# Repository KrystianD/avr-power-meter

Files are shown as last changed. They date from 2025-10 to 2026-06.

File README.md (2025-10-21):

avr-power-meter
======

Device for monitoring bidirectional DC energy usage using various shunt resistors. Designed to mount directly on the shunt.

This version targets 48 V systems (supports up to 85 V on the sensing side).

It is galvanically isolated from the power supply to prevent ground loops.

It communicates via the Modbus RTU protocol over an RS-485 interface.

The core components are the `INA228` sensor and an `ATtiny1626` microcontroller.

### History

See the v1 (test) version in [[v1]](https://github.com/KrystianD/avr-power-meter/tree/v1) branch. \
See the v2 (for 24V systems) version in [[v2]](https://github.com/KrystianD/avr-power-meter/tree/v2) branch.

# Board

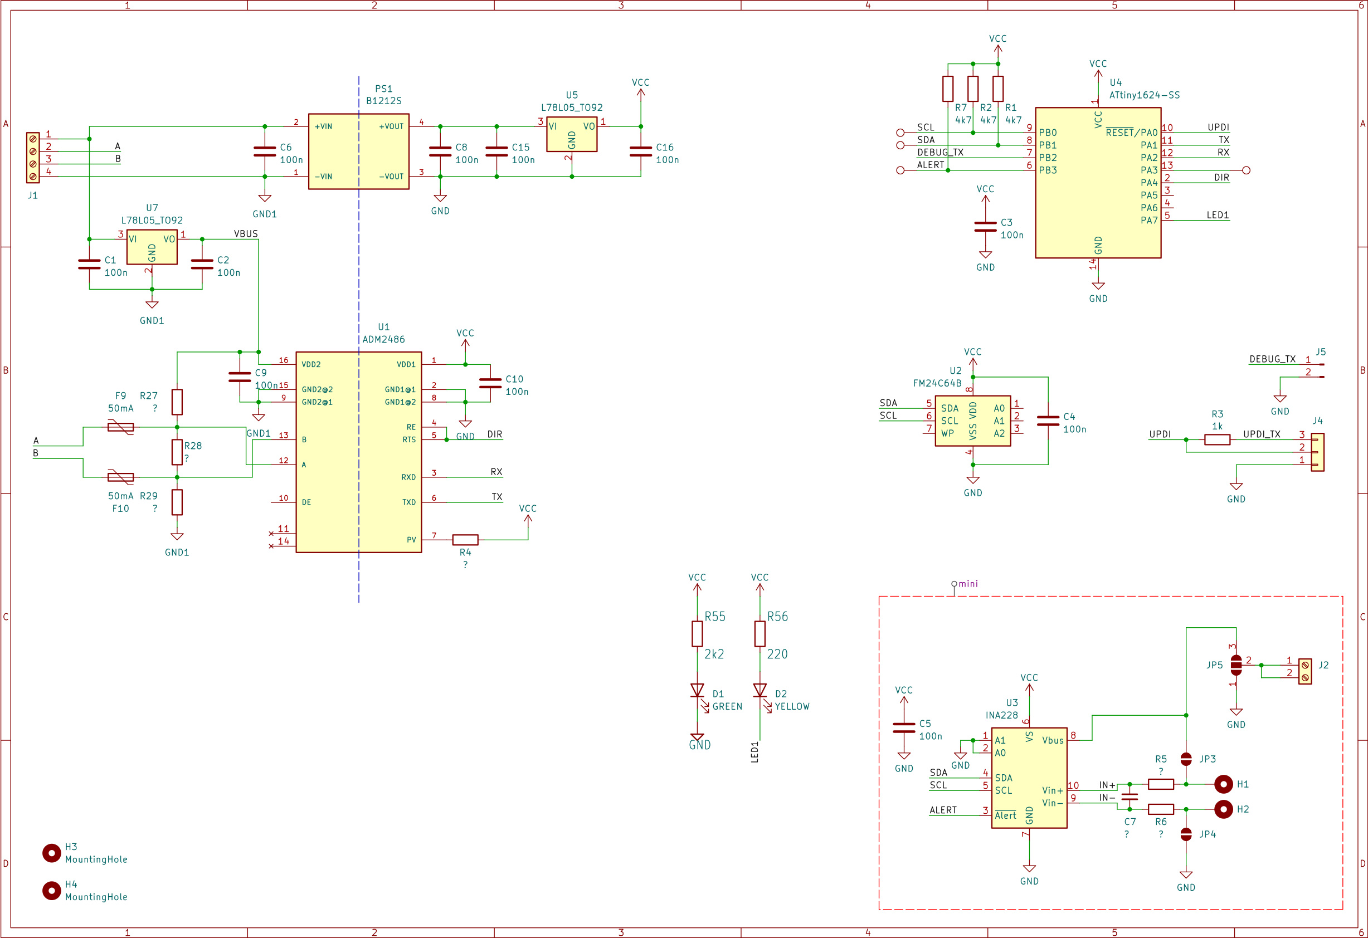
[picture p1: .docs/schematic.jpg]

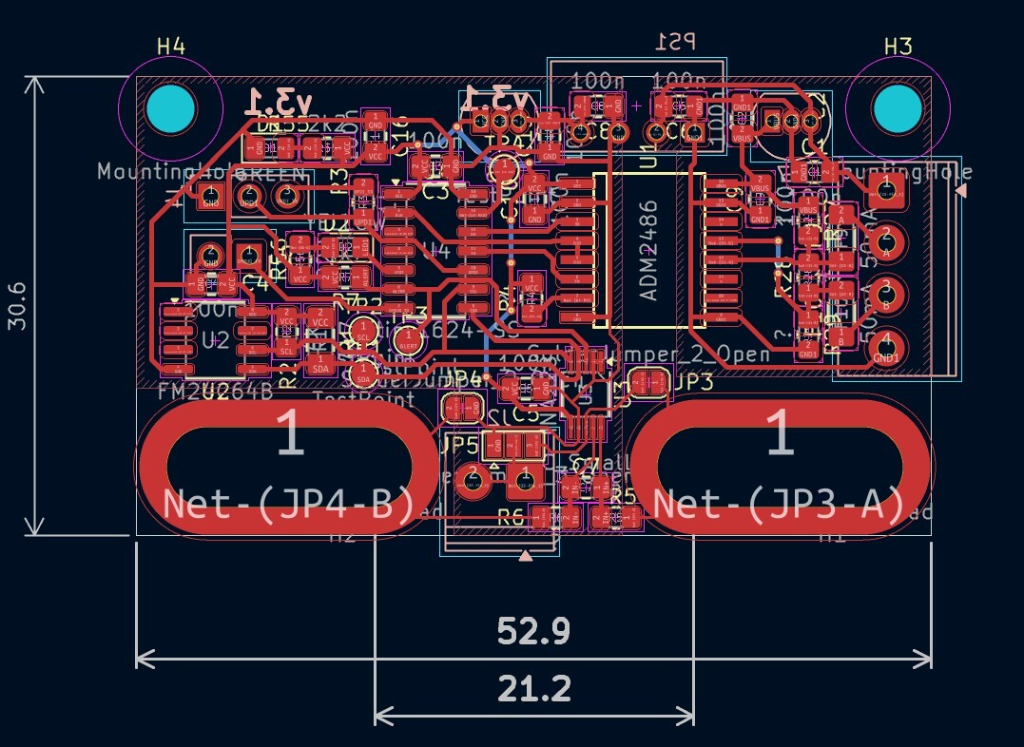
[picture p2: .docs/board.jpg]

<br/>
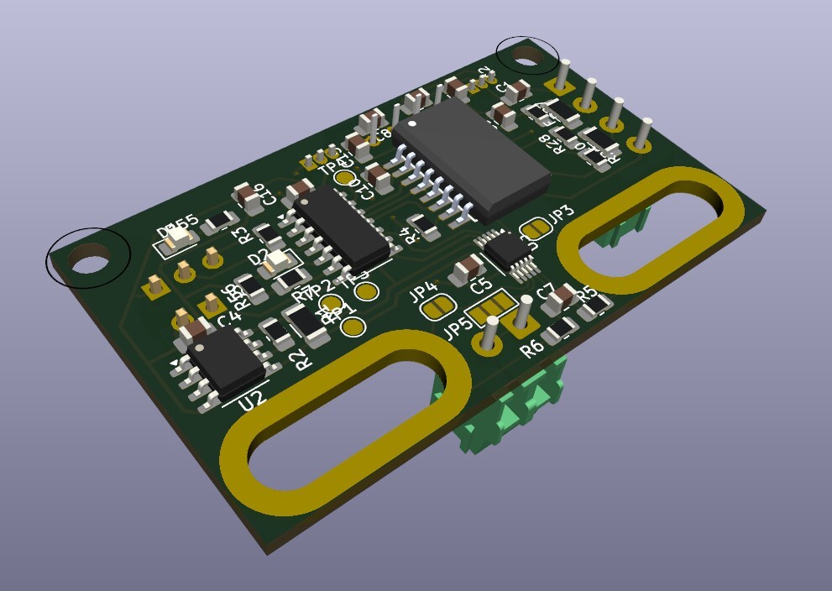
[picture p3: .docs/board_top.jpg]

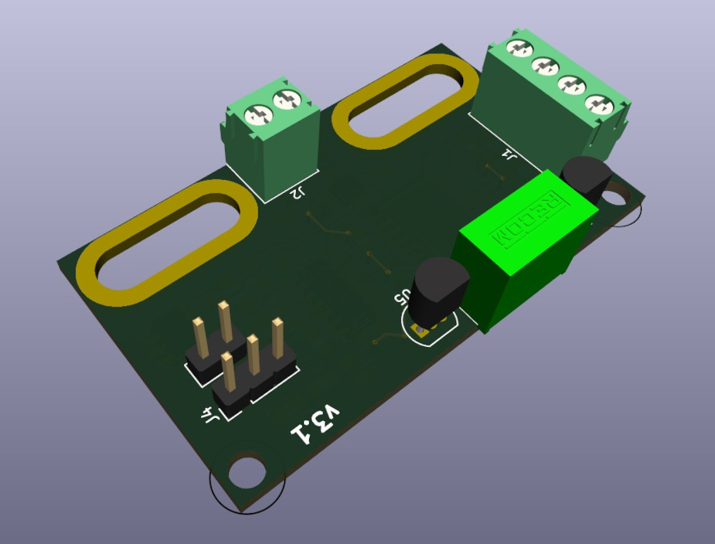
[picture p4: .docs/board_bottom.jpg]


# Photos

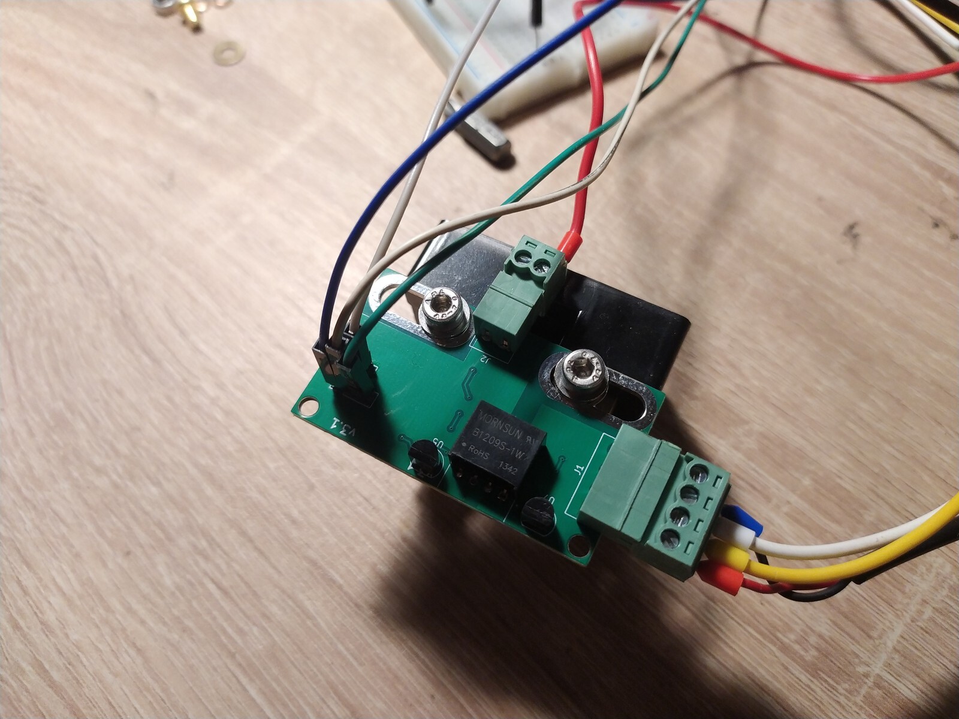
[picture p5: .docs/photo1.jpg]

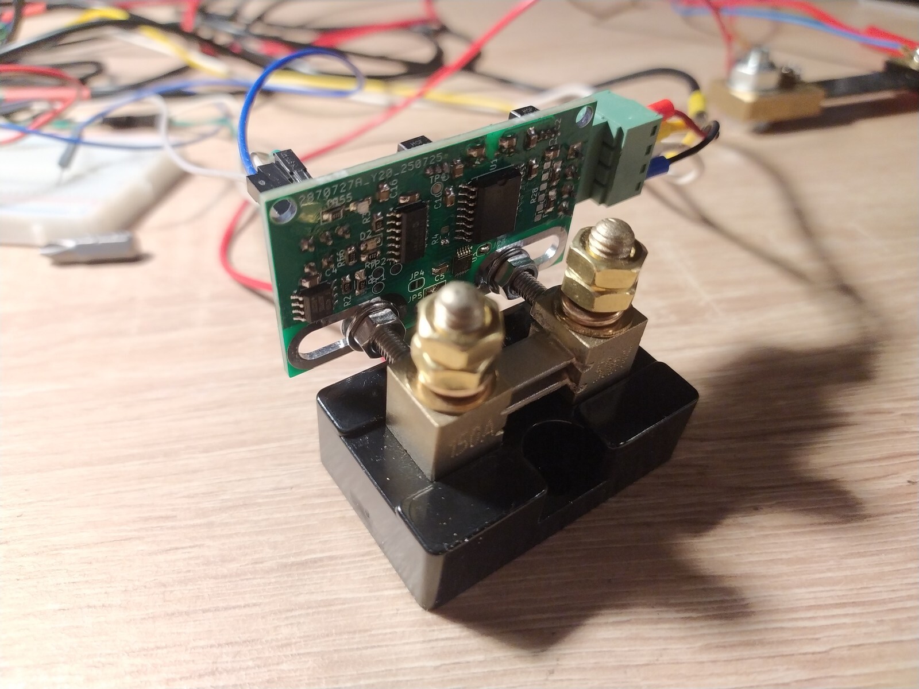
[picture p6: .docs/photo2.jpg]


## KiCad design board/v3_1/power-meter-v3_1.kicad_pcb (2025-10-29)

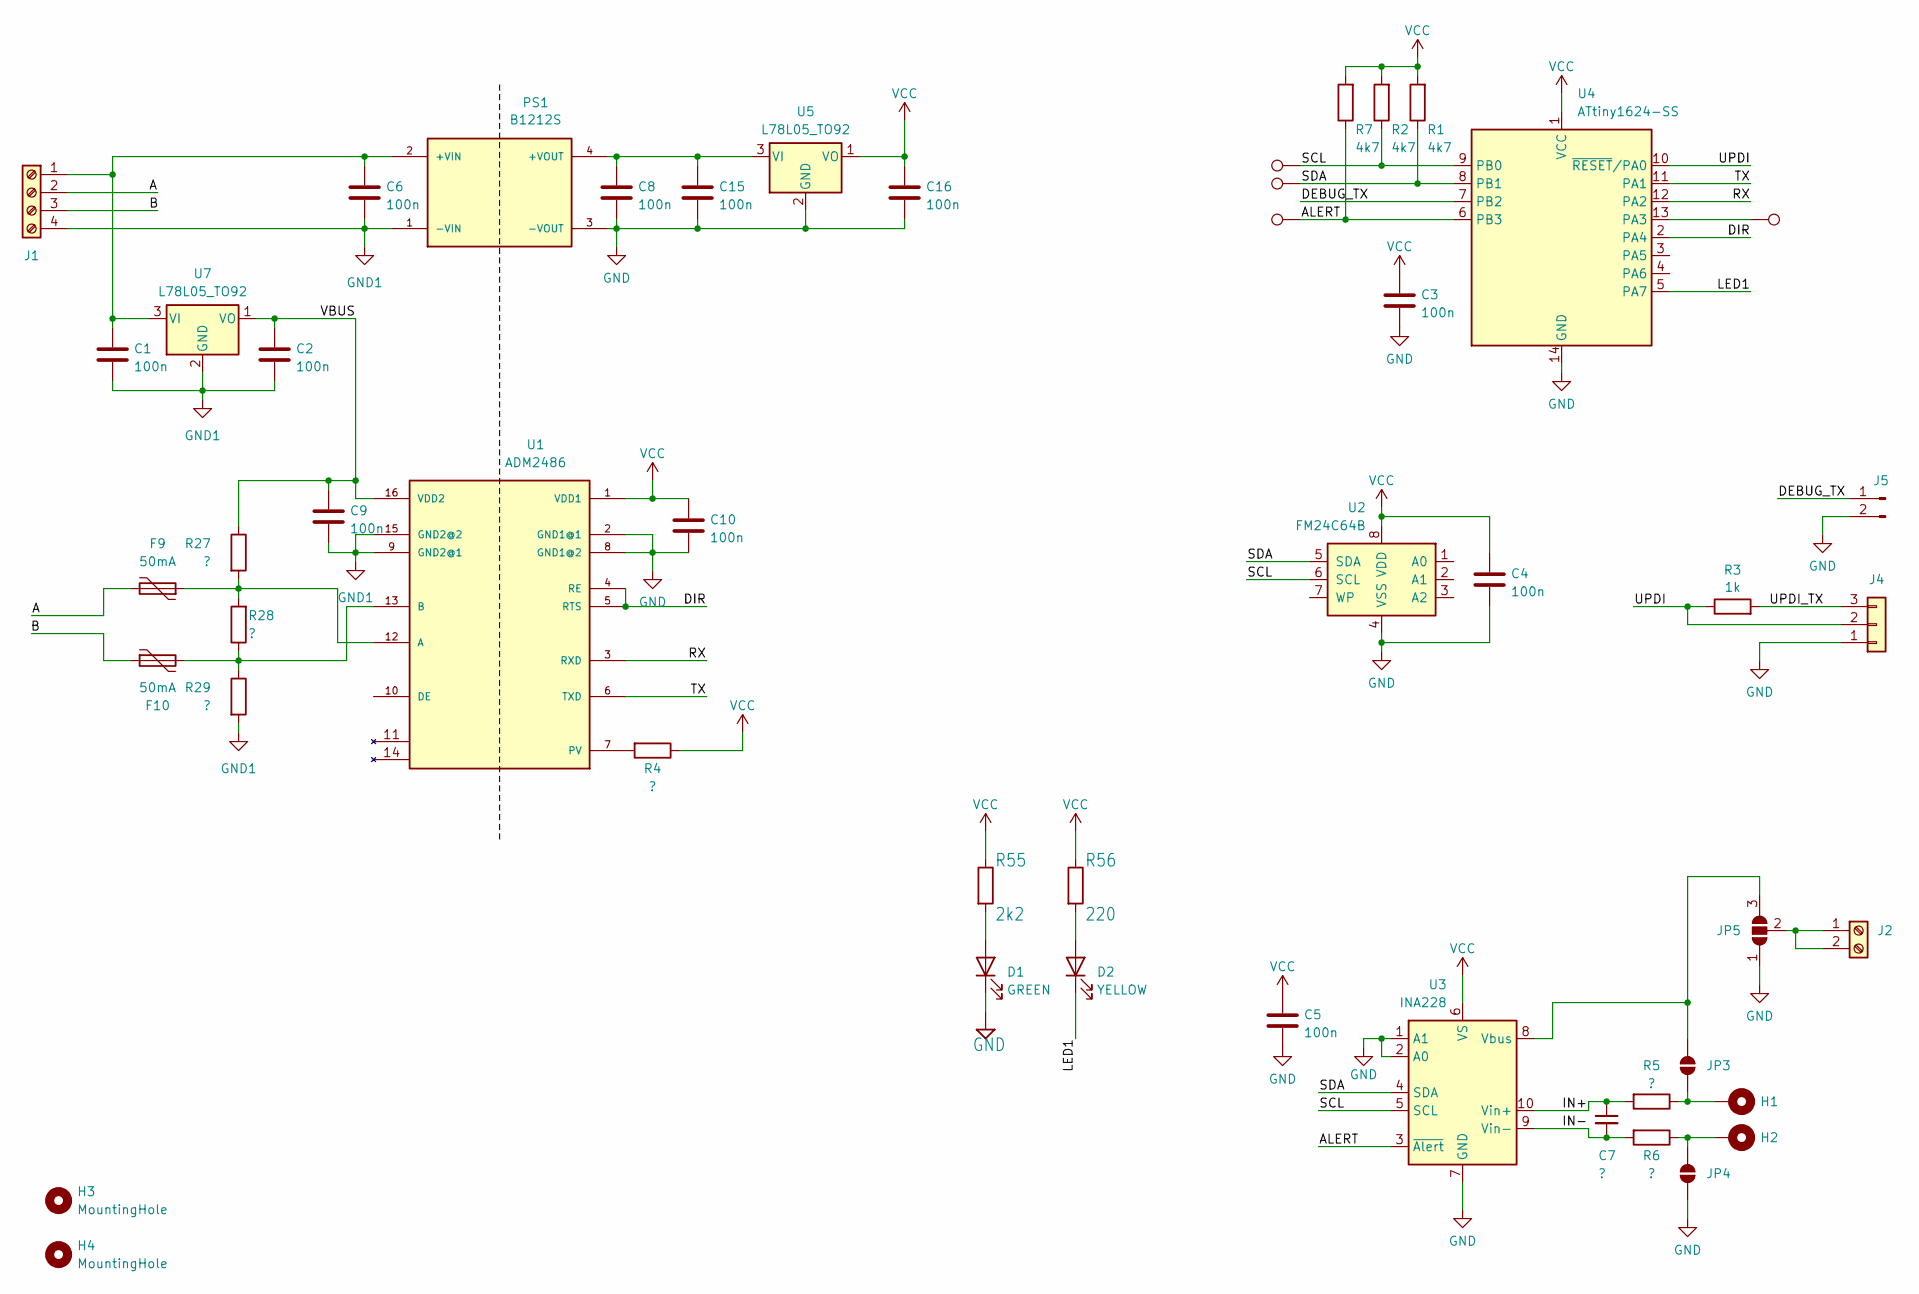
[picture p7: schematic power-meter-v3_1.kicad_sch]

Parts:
C1, C2, C3, C4, C5, C6, C8, C9, C10, C15, C16: 100n; C_0805_2012Metric_Pad1.18x1.45mm_HandSolder
C7: ?; C_0805_2012Metric_Pad1.18x1.45mm_HandSolder
D1: GREEN; LED_0805_2012Metric_Pad1.15x1.40mm_HandSolder
D2: YELLOW; LED_0805_2012Metric_Pad1.15x1.40mm_HandSolder
F9, F10: 50mA; R_1206_3216Metric_Pad1.30x1.75mm_HandSolder
H1, H2: MountingHole_Pad; M5-shunt-pad
H3, H4: MountingHole; MountingHole_3.2mm_M3
J1: Screw_Terminal_01x04; TerminalBlock_Phoenix_PT-1,5-4-3.5-H_1x04_P3.50mm_Horizontal
J2: Screw_Terminal_01x02; TerminalBlock_Phoenix_PT-1,5-2-3.5-H_1x02_P3.50mm_Horizontal
J4: Conn_01x03; PinHeader_1x03_P2.54mm_Vertical
J5: Conn_01x02_Pin; PinHeader_1x02_P2.54mm_Vertical
JP3, JP4: SolderJumper_2_Open; SolderJumper-2_P1.3mm_Open_RoundedPad1.0x1.5mm
JP5: SolderJumper_3_Open; SolderJumper-3_P1.3mm_Open_Pad1.0x1.5mm
PS1: B1212S; CONV_RO-0505S; PARTREV 3
R1: 4k7; R_1206_3216Metric_Pad1.30x1.75mm_HandSolder
R2, R7: 4k7; R_0805_2012Metric_Pad1.20x1.40mm_HandSolder
R3: 1k; R_0805_2012Metric_Pad1.20x1.40mm_HandSolder
R4, R5, R6, R27, R28, R29: ?; R_0805_2012Metric_Pad1.20x1.40mm_HandSolder
R55: 2k2; R_0805_2012Metric_Pad1.20x1.40mm_HandSolder
R56: 220; R_0805_2012Metric_Pad1.20x1.40mm_HandSolder
TP1, TP2, TP3, TP4: TestPoint; TestPoint_Pad_D1.5mm
U1: ADM2486; SOIC16R
U2: FM24C64B; SOIC-8_3.9x4.9mm_P1.27mm
U3: INA228; VSSOP-10_3x3mm_P0.5mm
U4: ATtiny1624-SS; SOIC-14_3.9x8.7mm_P1.27mm
U5, U7: L78L05_TO92; TO-92_Inline

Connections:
/A: F9.2, J1.2
/ALERT: R7.1, TP3.1 (1_1), U3.3 (~Alert), U4.6 (PB3)
/B: F10.1, J1.3
/DEBUG_TX: J5.1, U4.7 (PB2)
/DIR: U1.4 (RE), U1.5 (RTS), U4.2 (PA4)
/IN+: C7.1, R5.2, U3.10 (Vin+)
/IN-: C7.2, R6.2, U3.9 (Vin-)
/LED1: D2.1 (K), U4.5 (PA7)
/RX: U1.3 (RXD), U4.12 (PA2)
/SCL: R2.1, TP2.1 (1_1), U2.6 (SCL), U3.5 (SCL), U4.9 (PB0)
/SDA: R1.1, TP1.1 (1_1), U2.5 (SDA), U3.4 (SDA), U4.8 (PB1)
/TX: U1.6 (TXD), U4.11 (PA1)
/UPDI: J4.2, R3.1, U4.10 (~RESET/PA0)
/UPDI_TX: J4.3, R3.2
/VBUS: C2.2, C9.2, R27.1, U1.16 (VDD2), U7.1 (VO)
GND: C3.1, C4.1, C5.1, C8.1, C10.1, C15.1, C16.1, D1.1 (K), J4.1, J5.2, JP4.1 (A), JP5.1 (A), PS1.3 (-VOUT), U1.2 (GND1@1), U1.8 (GND1@2), U2.4 (VSS), U3.1 (A1), U3.2 (A0), U3.7 (GND), U4.14 (GND), U5.2 (GND)
GND1: C1.1, C2.1, C6.1, C9.1, J1.4, PS1.1 (-VIN), R29.2, U1.9 (GND2@1), U1.15 (GND2@2), U7.2 (GND)
unnamed: D1.2 (A), R55.2
unnamed: D2.2 (A), R56.2
unnamed: C1.2, C6.2, J1.1, PS1.2 (+VIN), U7.3 (VI)
unnamed: J2.1, J2.2, JP5.2 (C)
unnamed: H1.1 (1_1), JP3.1 (A), R5.1
unnamed: JP3.2 (B), JP5.3 (B), U3.8 (Vbus)
unnamed: H2.1 (1_1), JP4.2 (B), R6.1
unnamed: C8.2, C15.2, PS1.4 (+VOUT), U5.3 (VI)
unnamed: F9.1, R27.2, R28.2, U1.12 (A)
unnamed: F10.2, R28.1, R29.1, U1.13 (B)
unnamed: R4.2, U1.7 (PV)
unnamed: TP4.1 (1_1), U4.13 (PA3)
VCC: C3.2, C4.2, C5.2, C10.2, C16.2, R1.2, R2.2, R4.1, R7.2, R55.1, R56.1, U1.1 (VDD1), U2.8 (VDD), U3.6 (VS), U4.1 (VCC), U5.1 (VO)

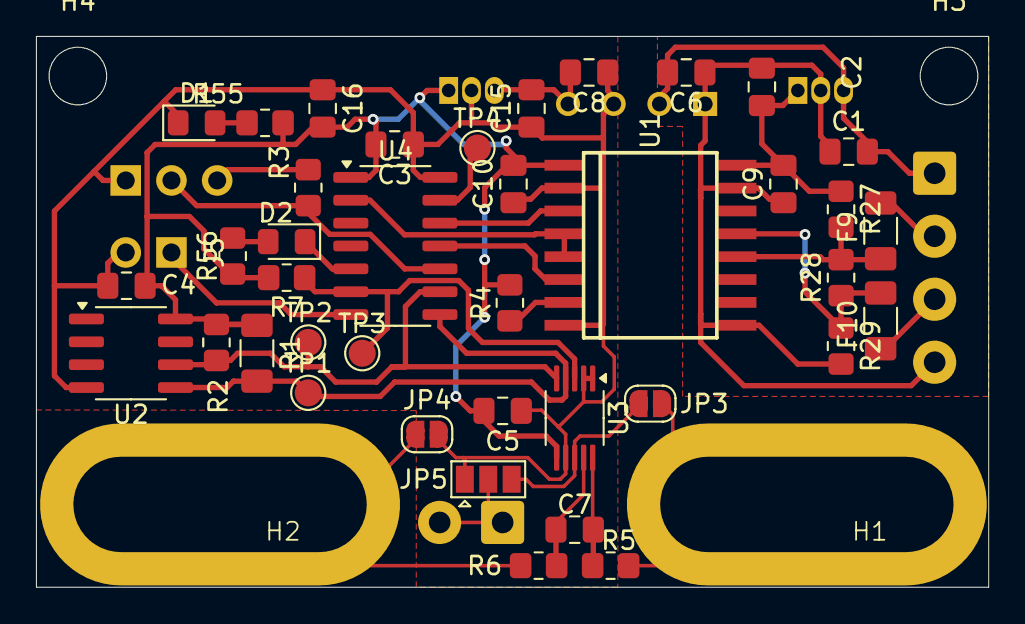
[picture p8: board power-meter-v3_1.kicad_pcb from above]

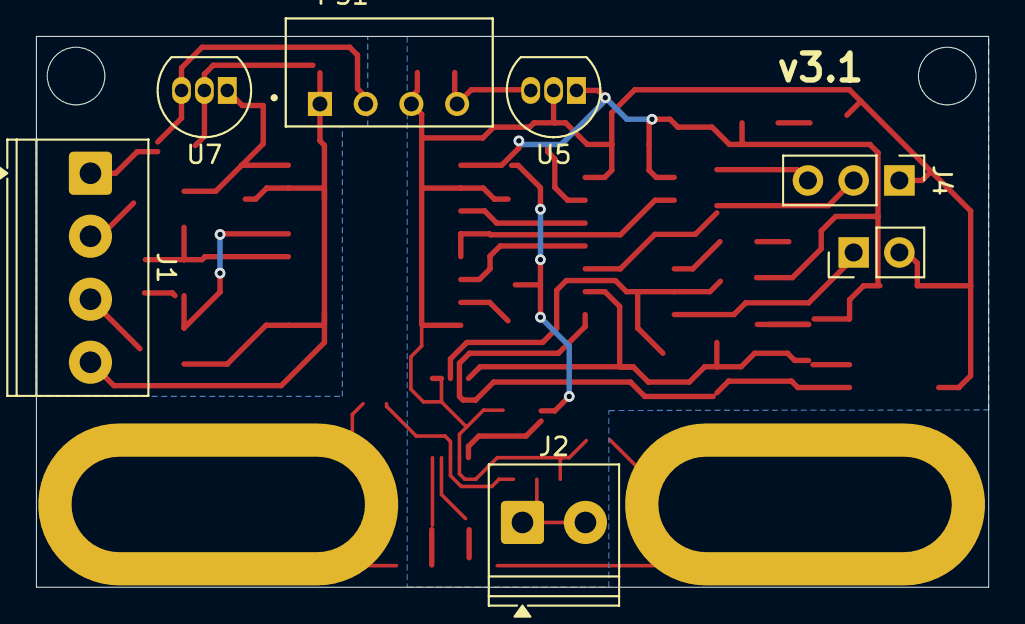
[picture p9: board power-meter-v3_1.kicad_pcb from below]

Board: 2 copper layers, 52.9 x 30.6 mm, 50 parts (7 on the bottom side), 30 nets.

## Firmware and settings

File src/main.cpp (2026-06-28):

#include <stdint.h>

#include <ksystem.h>

#include "ina228.h"
#include "global.h"
#include <kADC.h>

float currentLsb;

void reboot();

void setup()
{
	scl.input();
	sda.input();
	led.low();

	Config config = global::eeConfig.get();

#define TWI_BAUD(freq, t_rise) (((F_CPU / freq) / 2) - (5 + (((F_CPU / 1000000) * t_rise) / 2000)))

	TWI0.MBAUD = TWI_BAUD(100000, 600);
	TWI0.MCTRLA = TWI_ENABLE_bm;
	TWI0.MSTATUS = TWI_BUSSTATE_IDLE_gc;

	ina228::Configuration cfg{};
	cfg.reset = true;
	ina228::writeConfig(cfg);

	ina228::AdcConfiguration conf = {
		.avg = config.averages,
		.vtempct = ina228::ConversionTime::Conv50us,
		.vshuntct = config.conversionTime,
		.vbusct = config.conversionTime,
		.mode = ina228::Mode::ContinuousTemperatureBusShunt,
	};

	ina228::writeAdcConfig(conf);
	ina228::writeRegister16(ina228::Registers::DIAG_ALRT, _BV(14));

	currentLsb = (float)config.shuntRatedCurrent_A / 524288.0f; // 2^19
	uint16_t shuntCal = (uint16_t)(100000.0f * (float)config.shuntRatedVoltageDrop_mV / 1000.0f / 4.0);

	ina228::writeRegister16(ina228::Registers::SHUNT_CAL, shuntCal);

	Modbus.start(config.slaveId);
}

uint16_t getMcuSupplyVoltage_mV()
{
	kADC::configureAll<8, ADC_REFSEL_1024MV_gc, 20>();

	uint16_t adc_voltDiv10 = kADC::doConversion12Bit(ADC_MUXPOS_VDDDIV10_gc);
	// Vsupply_mV = adc_voltDiv10 / 4096 * 1024 * 10
	uint16_t Vsupply_mV = adc_voltDiv10 * 5 / 2;

	return Vsupply_mV;
}

void loop()
{
	static int i = 0;
	if (alert.isLow()) {
		ina228::clearStatus();

		ina228::readDieTempValue(global::state.raw_dieTemp);
		ina228::readVbusValue(global::state.raw_vbus);
		ina228::readVshuntValue(global::state.raw_vshunt);
		ina228::readCurrentValue(global::state.raw_current);
		ina228::readPowerValue(global::state.raw_power);
		ina228::readEnergyValue(global::state.raw_energy);
		ina228::readChargeValue(global::state.raw_charge);

		uint16_t mcuVoltage = getMcuSupplyVoltage_mV();

		constexpr float Scale_mV = 1000000.0f;
		constexpr float Scale_nV = 1000000000.0f;

		global::state.dieTemp = (float)global::state.raw_dieTemp * (7.8125f / 1000.0f);
		global::state.vbus = (float)global::state.raw_vbus * (195.3125f / Scale_mV);
		global::state.vshunt = (float)global::state.raw_vshunt * (312.5f / Scale_nV);
		global::state.current = currentLsb * (float)global::state.raw_current;
		global::state.power = currentLsb * (float)global::state.raw_power * 3.2f /* [W] */;
		global::state.energy = currentLsb * (float)global::state.raw_energy * (3.2f * 16) /* [Ws] */ / 3600.0f /* [Wh] */;
		global::state.charge = currentLsb * (float)global::state.raw_charge /* [As] */ / 3600.0f /* [Ah] */;
		global::state.mcuVoltage = mcuVoltage;

		i++;
		if (i == 100) {
			printf("----\r\n");
			printf("DIETEMP = %10d, %10.2f\r\n", global::state.raw_dieTemp, global::state.dieTemp);
			printf("VBUS    = %10ld, %10.2f\r\n", global::state.raw_vbus, global::state.vbus);
			printf("VSHUNT  = %10ld, %10.2f\r\n", global::state.raw_vshunt, global::state.vshunt);
			printf("CURRENT = %10ld, %10.2f\r\n", global::state.raw_current, global::state.current);
			printf("POWER   = %10ld, %10.2f\r\n", global::state.raw_power, global::state.power);
			printf("ENERGY  = %10.0f, %10f\r\n", (float)global::state.raw_energy, global::state.energy);
			printf("CHARGE  = %10.0f, %10f\r\n", (float)global::state.raw_charge, global::state.charge);
			i = 0;
		}

		if (global::requestRebootCounter > 0) {
			global::requestRebootCounter--;

			if (global::requestRebootCounter == 0) {
				reboot();
			}
		}
	}
}

void reboot()
{
	_PROTECTED_WRITE(RSTCTRL.SWRR, 1);
}

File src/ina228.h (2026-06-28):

#pragma once

#include <stdint.h>

namespace ina228
{
enum class Mode : uint8_t
{
	Shutdown = 0,
	TriggeredBus = 1,
	TriggeredShunt = 2,
	TriggeredBusShunt = 3,
	TriggeredTemperature = 4,
	TriggeredTemperatureBus = 5,
	TriggeredTemperatureShunt = 6,
	TriggeredTemperatureBusShunt = 7,

	Shutdown2 = 8 + 0,
	ContinuousBus = 8 + 1,
	ContinuousShunt = 8 + 2,
	ContinuousBusShunt = 8 + 3,
	ContinuousTemperature = 8 + 4,
	ContinuousTemperatureBus = 8 + 5,
	ContinuousTemperatureShunt = 8 + 6,
	ContinuousTemperatureBusShunt = 8 + 7,
};

enum class Averages : uint8_t
{
	Min = 0,
	Average1 = 0,
	Average4 = 1,
	Average16 = 2,
	Average64 = 3,
	Average128 = 4,
	Average256 = 5,
	Average512 = 6,
	Average1024 = 7,
	Max = Average1024,
};

enum class ConversionTime : uint8_t
{
	Min = 0,
	Conv50us = 0,
	Conv84us = 1,
	Conv150us = 2,
	Conv280us = 3,
	Conv540us = 4,
	Conv1052us = 5,
	Conv2074us = 6,
	Conv4120us = 7,
	Max = Conv4120us,
};

enum class AdcRange : uint8_t
{
	Scale163_84mV = 0,
	Scale40_96mV = 1,
};

enum class Registers : uint8_t
{
	CONFIG = 0,
	ADC_CONFIG = 1,
	SHUNT_CAL = 2,
	VSHUNT = 4,
	VBUS = 5,
	DIETEMP = 6,
	CURRENT = 7,
	POWER = 0x08,
	ENERGY = 0x09,
	CHARGE = 0x0a,
	DIAG_ALRT = 0x0b,
};

#pragma pack(1)
struct Configuration
{
	int reserved : 4;
	AdcRange adcRange : 1;
	bool tempCompensation : 1;
	int conversionDelay : 8;
	bool resetAccumulators : 1;
	bool reset : 1;
};

struct AdcConfiguration
{
	Averages avg : 3;
	ConversionTime vtempct : 3;
	ConversionTime vshuntct : 3;
	ConversionTime vbusct : 3;
	Mode mode : 4;
};
#pragma pack()

bool writeRegister16(Registers reg, uint16_t value);
bool readRegister16(Registers reg, int32_t* value);
bool readRegister24(Registers reg, int32_t* value);
bool readRegister40(Registers reg, uint64_t* value);
bool readRegister40s(Registers reg, int64_t* value);

bool writeConfig(const Configuration& config);
bool writeAdcConfig(const AdcConfiguration& config);
bool clearStatus();

bool readDieTempValue(int16_t& val);
bool readVbusValue(uint32_t& val);
bool readVshuntValue(int32_t& val);
bool readCurrentValue(int32_t& val);
bool readPowerValue(int32_t& val);
bool readEnergyValue(int64_t& val);
bool readChargeValue(int64_t& val);
}

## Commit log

2025-10-29 minor schematic updates
    [power-meter-v3_1.kicad_pcb, power-meter-v3_1.kicad_sch]
2026-06-28 board update
    [power-meter-v3_1.kicad_sch]
2026-06-28 reboot asynchronously to properly send modbus ack
    [main.cpp]
2026-06-28 exposed mcu voltage as a modbus register
